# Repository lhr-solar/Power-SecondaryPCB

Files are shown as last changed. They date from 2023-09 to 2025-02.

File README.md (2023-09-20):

# Power-SecondaryPCB 
Author: Pratyush Patra and Jason Kacines

This board takes inputs from the DCDC converter and the Supplemental Battery and selects which source to output to the fuse box. DCDC is the power from the high voltage primary battery pack that gets stepped down to 12V through the DCDC converter. The supplemental battery pack is the low voltage 12V NiMH battery pack. When DCDC is on, the board will select DCDC, and when DCDC is off, the board will select the Supplemental Battery. The supplemental should only be selected during ignition and the fault state. The board selects the source using a 10V zener diode that will breakdown once DCDC is above 10V.

This board also interfaces with both the Supplemental Monitoring PCB and Ignition Switch:
- For the Supplemental Monitoring PCB, this board sends the voltage of the Supplemental Battery out from J1. 
- For the Ignition Switch, this board sends Supplemental Power to the Controls Board through J6, which is then routed back to this board through J7 when the Ignition Switch is changed from the off position. When this signal is sent to J7, it is routed to the gate of Q3 which turns on the NMOS and starts sending power to the fuse box.

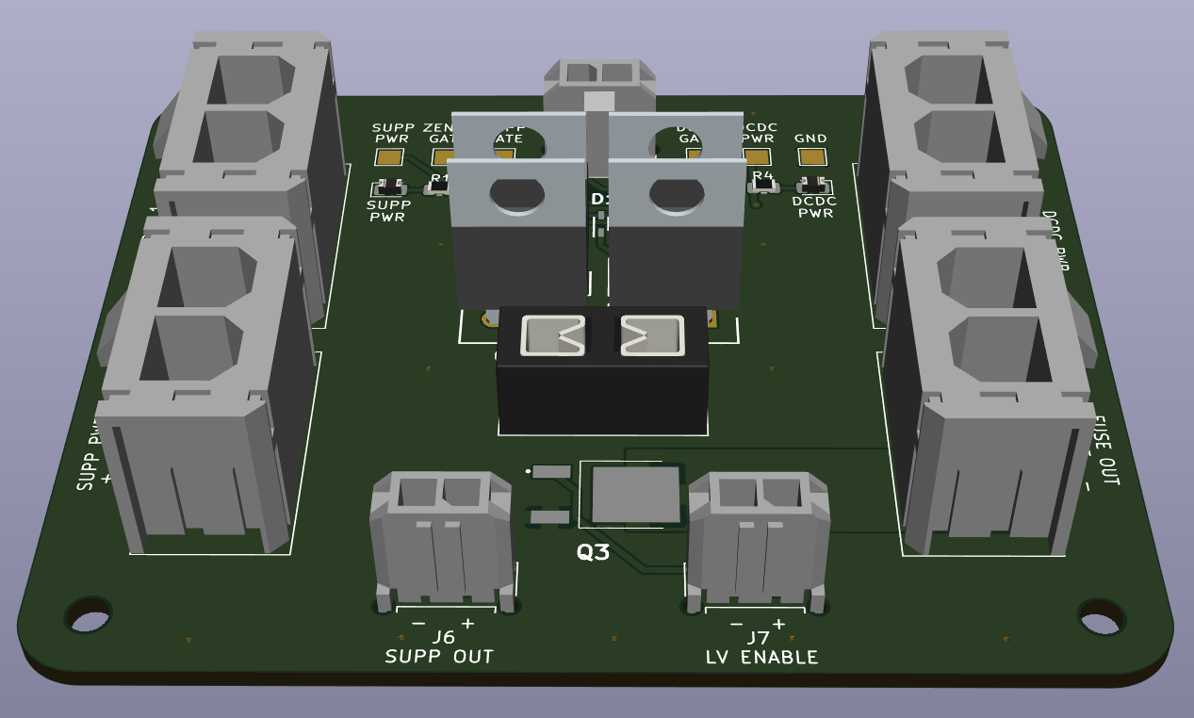
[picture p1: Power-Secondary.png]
Power-Secondary


## BOM
[**Interactive BOM (Must download and open in browser)**](bom/ibom.html)

[**Mouser Cart**](https://www.mouser.com/ProjectManager/ProjectDetail.aspx?AccessID=da938bf7b6)

## Connectors
| # | Name | Type | Ideal Voltage | Notes |
| - | - | - | - | - |
| J1  | SUPP PWR MON | 1x02_P3.00mm_Vertical Female | +12V | 9.9 mm tall |
| J2  | SUPP PWR 1 | 1x02_P7.49mm_Vertical Female |+12V | 14.76 mm tall |
| J3  | SUPP PWR 2 | 1x02_P7.49mm_Vertical Female | +12V | 14.76 mm tall |
| J4  | DCDC PWR | 1x02_P7.49mm_Vertical Female | +12V | 14.76 mm tall |
| J5  | FUSE OUT | 1x02_P7.49mm_Vertical Female | +12V | 14.76 mm tall |
| J6  | SUPP OUT | 1x02_P3.00mm_Vertical Female | +12V | 9.9 mm tall |
| J7  | LV ENABLE | 1x02_P3.00mm_Vertical Female | +12V | 9.9 mm tall |

## PCB


## Schematic


## Additional Notes
The tallest components are the Power MOSFETs(Q1A1, Q1A2, Q1A3, Q1A4) which are 18.5 mm tall and the connectors which are 14.76 mm tall.

## Current Board Concerns(8.26.2023)
- If the two Supplemental Batteries are at different voltage, don't want to charge batteries.
- If the two Supplemental Batteries are above 12V and DCDC is off, don't want to overvolt LV systems. 
        Can tolerate 12.8V.
- Should we use heat sinks for the MOSFET or switch to SMD in case we need to increase current draw in the future
- In future switch to this mosfet, https://www.mouser.com/datasheet/2/196/Infineon_IRFR5305_DataSheet_v01_01_EN-3166466.pdf

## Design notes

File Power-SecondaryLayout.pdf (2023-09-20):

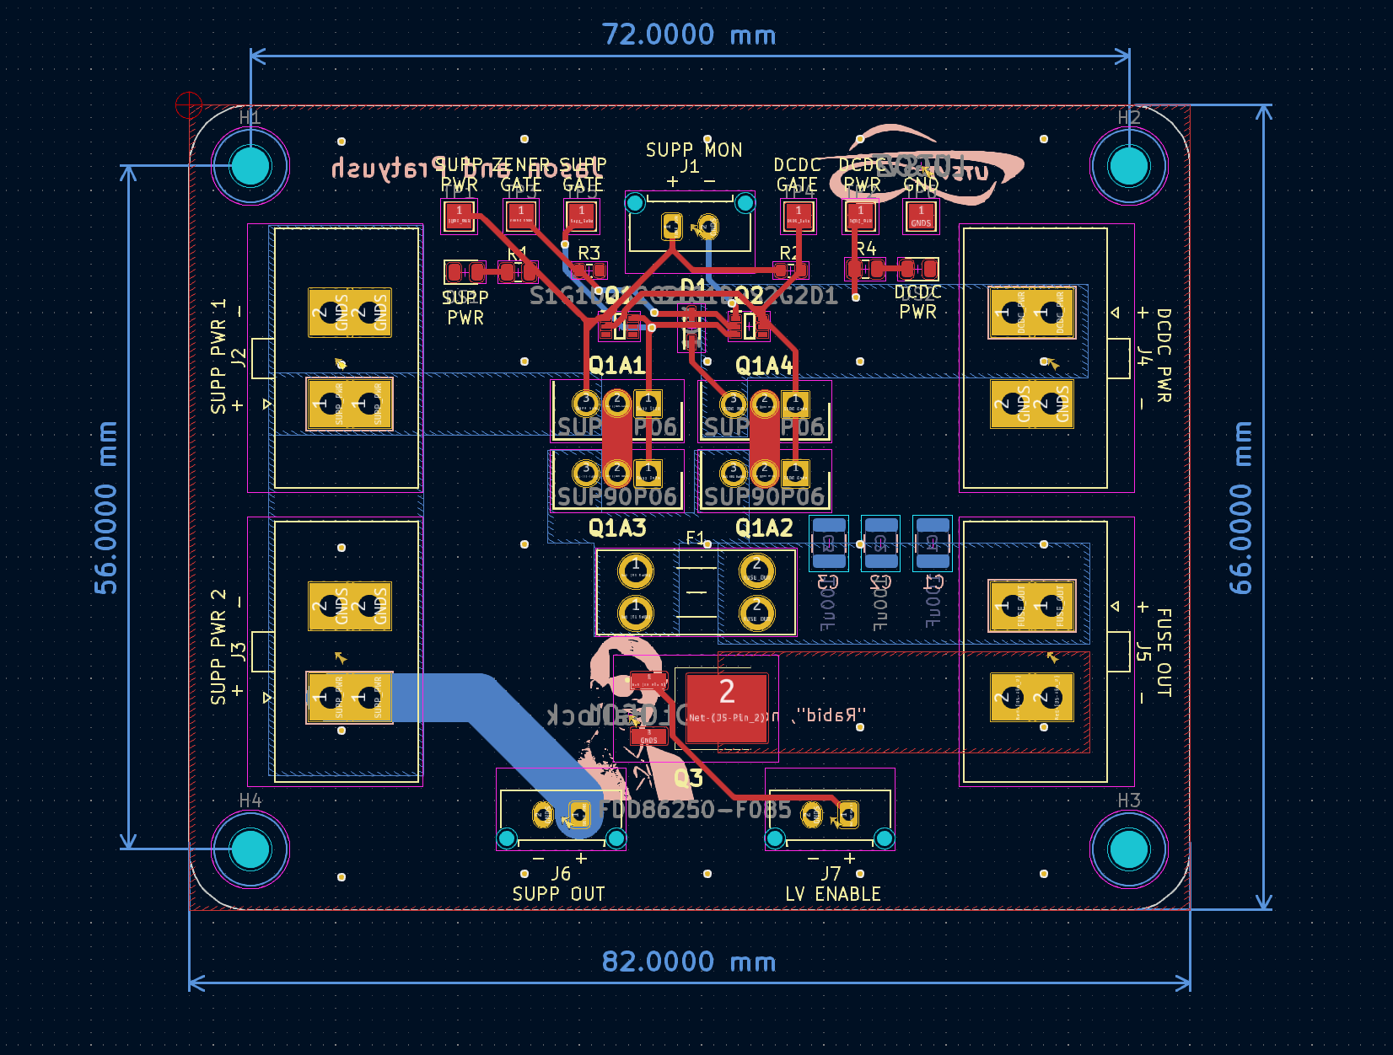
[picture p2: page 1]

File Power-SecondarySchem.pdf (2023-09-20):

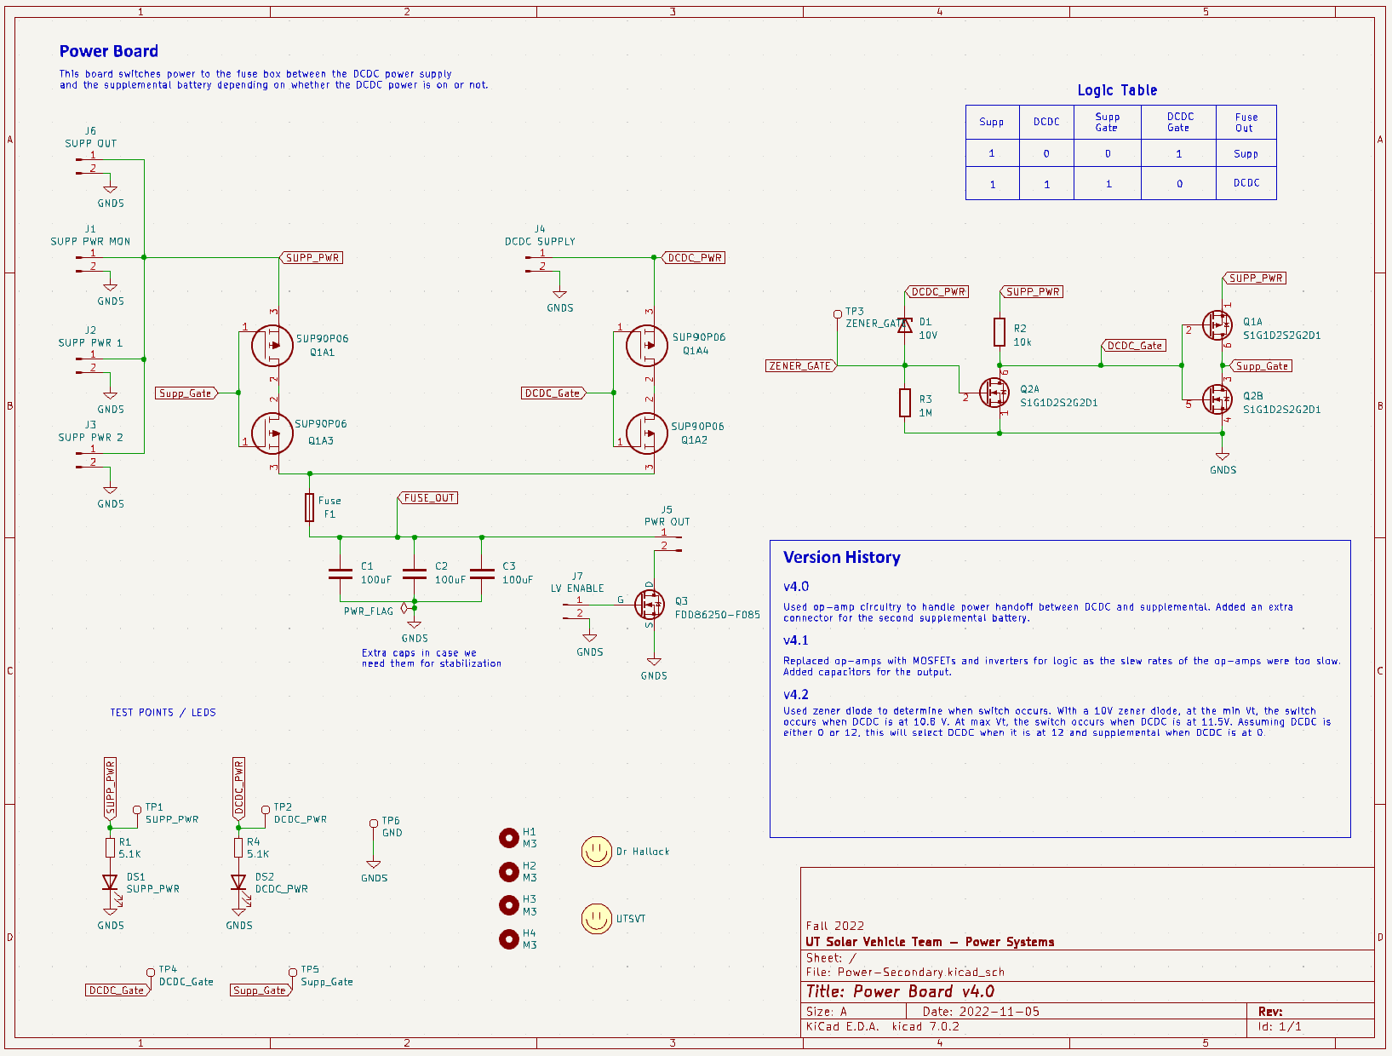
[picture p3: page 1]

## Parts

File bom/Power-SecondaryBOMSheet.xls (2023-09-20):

Mouser # | Mfr. # | Manufacturer | Description | Order Qty. | Price (USD) | Ext.: (USD)
781-SUP90P06-09L-E3 | SUP90P06-09L-E3 | Vishay | Power PMOS(Q1A1, Q1A2, Q1A3, Q1A4) | 4 | $5.56 | $22.24
755-UM6J1NTN | UM6J1NTN | ROHM Semiconductor | Logic PMOS(Q1) | 1 | $0.47 | $0.47
755-UM6K1NTN | UM6K1NTN | ROHM Semiconductor | Logic NMOS(Q2) | 1 | $0.42 | $0.42
538-43160-0102 | 43160-0102 | Molex | Power Connector(J2, J3, J4, J5) | 4 | $1.13 | $4.52
576-0297025.L | 0297025.L | Littelfuse | Fuse | 1 | $0.52 | $0.52
534-3568 | 3568 | Keystone Electronics | Fuse Holder(F1) | 1 | $0.92 | $0.92
604-APTD2012LCGCK | APTD2012LCGCK | Kingbright | LEDs(DS1, DS2) | 2 | $0.40 | $0.80
538-43650-0215 | 43650-0215 | Molex | Monitoring Connector(J1, J6, J7) | 3 | $0.97 | $2.91
80-C0805C106M3PACLR | C0805C106M3PAC7210 | KEMET | Capacitors(C1, C2, C3) | 3 | $0.40 | $1.20
71-CRCW1210J-5.1K-E3 | CRCW12105K10JNEA | Vishay | 5.1k Resistor(R1, R4) | 2 | $0.21 | $0.42
603-RC0603FR-071ML | RC0603FR-071ML | YAGEO | 1M Resistor(R3) | 1 | $0.10 | $0.10
603-AT0603FRD0710KL | AT0603FRD0710KL | YAGEO | 10k Resistor(R2) | 1 | $0.33 | $0.33
771-BZX384-A5V1-QX | BZX384-A5V1-QX | Nexperia | Zener Diode(D1) | 1 | $0.41 | $0.41
863-FDD86250-F085 (https://www.mouser.com/ProductDetail/863-FDD86250-F085) | FDD86250-F085 (https://www.mouser.com/ProductDetail/863-FDD86250-F085) | Onsemi | Power NMOS(Q3) | 1 | $2.28 | $2.28

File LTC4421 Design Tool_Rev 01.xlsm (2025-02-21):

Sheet: Design
Please enter the data in white cells
LTC4421 Design Tool
Primary Input Supply
Highest Priority Input Voltage | 12 | V
Over Voltage Rising | 13 | V
Under Voltage Rising | 11.5 | V
Under Voltage Falling | 10.5 | V
Supply Tolerance | 1 | %
Current Limit | 25 | A
Load Current | 20 | A
OV UV Resistors
For Primary Input Supply
Resistor Netwrok Option | 3
Resistor Tolerance | 2 |  |  |  |  | E192 (0.5%)
Go to line#95 to continue design
Option 1 Resistor Calculations
Resistor Ladder Current | 10.00 | uA
OV1, UVR1, UVF1 Pin Leakage Current | 10.00 | nA
R1 + R2 + R3 + R4 | 1200.00 | kΩ
R1 | 46.15 | kΩ
R2 | 6.02 | kΩ
R3 | 4.97 | kΩ
R4 | 1142.86 | kΩ
Suggested Standard Resistor Values
R1 | 46.40 | kΩ |  |  |  | E96 (1%) | 96 | 1 | 0 | Active E | active %
R2 | 6.04 | kΩ |  |  |  | E192 (0.5%) | 192 | 0.5 | 1 | 192 | 0.5
R3 | 4.99 | kΩ |  |  |  | E192 (0.25%) | 192 | 0.25 | 0
R4 | 1140.00 | kΩ |  |  |  | E192 (0.1%) | 192 | 0.1 | 0
Selected Standard Resistor Values |  |  |  |  |  | min | max
R1 | 38.80 | kΩ |  |  |  | 38.606 | 38.994
R2 | 13.50 | kΩ |  |  |  | 13.4325 | 13.5675
R3 | 4.99 | kΩ |  |  |  | 4.96505 | 5.01495
R4 | 1140.00 | kΩ |  |  |  | 1134.3 | 1145.7
Resistor Tolerance | 0.50 | %
Worst Case Power Dissipation | 0.000114 | W |  |  |  | Resistor Power Rating
Recommended Power Rating of the Resistor | 0.05 | W |  |  |  | 0.05
 |  |  |  |  |  | 0.062
Actual Thresholds | Min | Typ | Max |  |  | 0.1
Actual Over Voltage Rising | 14.97 | 15.43 | 15.89 | V |  | 0.125
Actual Over Voltage Falling | 12.51 | 13.22 | 13.95 | V |  | 0.25
Actual Under Voltage Rising | 11.11 | 11.45 | 11.79 | V |  | 0.5
Actual Under Voltage Falling | 10.14 | 10.45 | 10.76 | V |  | 1
Option 2 Resistor Calculations
Current in Each Resistor Leg | 3.00 | uA
OV1, UVR1, UVF1 Pin Leakage Current | 10.00 | nA
Calculated Resistor Values
R_TOTAL each leg | 4000.00 | kΩ
R1 | 173.91 | kΩ
R2 | 16.56 | kΩ
R3 | 3809.52 | kΩ
R4 | 153.85 | kΩ
R5 | 3846.15 | kΩ
Suggested Standard Resistor Values
R1 | 174.00 | kΩ
R2 | 16.50 | kΩ
R3 | 3830.00 | kΩ
R4 | 154.00 | kΩ
R5 | 3830.00 | kΩ
Selected Standard Resistor Values |  |  |  |  |  | min | max
R1 | 221.00 | kΩ |  |  |  | 219.895 | 222.105
R2 | 110.00 | kΩ |  |  |  | 109.45 | 110.55
R3 | 3650.00 | kΩ |  |  |  | 3631.75 | 3668.25
R4 | 124.00 | kΩ |  |  |  | 123.38 | 124.62
R5 | 3830.00 | kΩ |  |  |  | 3810.85 | 3849.15
Resistor Tolerance | 0.50 | %
Worst Case Power Dissipation | 0.000383 | W
Recommended Power Rating of the Resistor | 0.05 | W
Actual Thresholds | Min | Typ | Max
Actual Over Voltage Rising | 15.47 | 15.94 | 16.42 | V
Actual Over Voltage Falling | 13.58 | 14.35 | 15.13 | V
Actual Under Voltage Rising | 8.74 | 9.01 | 9.27 | V
Actual Under Voltage Falling | 5.84 | 6.01 | 6.19 | V
Option 3 Resistor Calculations
Current in Each Resistor Leg | 2.00 | uA
OV1, UVR1, UVF1 Pin Leakage Current | 10.00 | nA
Calculated Resistor Values
R_TOTAL each leg | 6000.00 | kΩ
R1 | 285.71 | kΩ
R2 | 5714.29 | kΩ
R3 | 260.87 | kΩ
R4 | 5739.13 | kΩ
R5 | 230.77 | kΩ
R6 | 5769.23 | kΩ
Suggested Standard Resistor Values
R1 | 287.00 | kΩ
R2 | 5690.00 | kΩ
R3 | 261.00 | kΩ
R4 | 5760.00 | kΩ
R5 | 232.00 | kΩ
R6 | 5760.00 | kΩ
Selected Standard Resistor Values |  |  |  |  |  | min | max
R1 | 287.00 | kΩ |  |  |  | 285.565 | 288.435
R2 | 5760.00 | kΩ |  |  |  | 5731.2 | 5788.8
R3 | 261.00 | kΩ |  |  |  | 259.695 | 262.305
R4 | 5760.00 | kΩ |  |  |  | 5731.2 | 5788.8
R5 | 215.00 | kΩ |  |  |  | 213.925 | 216.075
R6 | 5760.00 | kΩ |  |  |  | 5731.2 | 5788.8
Resistor Tolerance | 0.50 | %
Worst Case Power Dissipation | 0.000576 | W
Recommended Power Rating of the Resistor | 0.05 | W
Actual Thresholds | Min | Typ | Max
Actual Over Voltage Rising | 13.49 | 13.90 | 14.31 | V
Actual Over Voltage Falling | 12.39 | 12.51 | 12.63 | V
Actual Under Voltage Rising | 11.20 | 11.53 | 11.88 | V
Actual Under Voltage Falling | 10.23 | 10.53 | 10.85 | V
Power Path
Current Limit | 25 | A
 | Min | Typ | Max
Power Dissipation across sense resistor netwrok during current limit | 0.5 | 0.625 | 0.75 | W
Allowed Power Dissipation per Sense Resistor | 1 | W
Desired Maximum Power Dissipation per Sense Resistor | 0.5 | W
Number of resistors required | 1
Equivalent Rsense of the power path should be | 1 | mΩ
Value of each resistor in Rsense should be | 1 | mΩ
Rsense Selected | 1 | mΩ
Sense Resistor Tolarance | 1 | %
Number of Sense Resistors Populated | 1
 | Min | Typ | Max
Effective Rsense | 0.99 | 1.00 | 1.01 | mΩ
 | Min | Typ | Max
Actual Current Limit | 19.80 | 25.00 | 30.30 | A
Actual Power Dissipation per Sense Resistor | 0.39 | 0.62 | 0.93 | W
Snubber
CSN1 | 10.00 | uF
RSN1 | 0.48 | Ω
Resistor Tolerance | E96 (1%)
Suggested RSN1 | 0.5 | Ω
Motor Boating
Voltage Source Input Resistance | 0.0090 | 0.0100 | 0.0110 | Ω
Voltage Drop due to Source Resistance | 0.1782178218 | 0.25 | 0.33 | V
Difference in UVrise and UVfall Voltage | 0.97 | 1.00 | 1.03 | V
High chance of Motor boating. Please set the UVrise and UVfall voltages further apart.
Secondary Input Supply
Secondary Input Voltage | 12 | V
Over Voltage Rising | 13 | V
Under Voltage Rising | 11.5 | V
Under Voltage Falling | 1900-01-09 | V
Supply Tolerance | 1 | %
Current Limit | 16.25 | A
Load Current | 20 | A
Go to line#256 to continue design
Option 1 Resistor Calculations
OV UV Resistors
Resistor Ladder Current | 10.00 | uA
OV2, UVR2, UVF2 Pin Leakage Current | 10.00 | nA
R5+R6+R7+R8 | 1200.00 | kΩ
R5 | 46.15 | kΩ
R6 | 6.02 | kΩ
R7 | 4.97 | kΩ
R8 | 1142.86 | kΩ
Suggested Standard Resistor Values
Resistor Tolerance | E96 (1%)
R5 | 46.40 | kΩ
R6 | 6.04 | kΩ
R7 | 4.99 | kΩ
R8 | 1140.00 | kΩ
Selected Standard Resistor Values |  |  |  |  |  | min | max
R5 | 38.80 | kΩ |  |  |  | 38.606 | 38.994
R6 | 13.50 | kΩ |  |  |  | 13.4325 | 13.5675
R7 | 9.65 | kΩ |  |  |  | 9.60175 | 9.69825
R8 | 1140.00 | kΩ |  |  |  | 1134.3 | 1145.7
Resistor Tolerance | 0.50 | %
Worst Case Power Dissipation | 0.000114 | W
Recommended Power Rating of the Resistor | 0.05 | W
Actual Thresholds | Min | Typ | Max
Actual Over Voltage Rising | 15.03 | 15.49 | 15.95 | V
Actual Over Voltage Falling | 12.51 | 13.22 | 13.95 | V
Actual Under Voltage Rising | 11.15 | 11.49 | 11.83 | V
Actual Under Voltage Falling | 9.42 | 9.70 | 9.99 | V
Option 2 Resistor Calculations
Current in Each Resistor Leg | 3.00 | uA
OV1, UVR1, UVF1 Pin Leakage Current | 10.00 | nA
Calculated Resistor Values
R_TOTAL each leg | 4000.00 | kΩ
R6 | 173.91 | kΩ
R7 | 16.56 | kΩ
R8 | 3809.52 | kΩ
R9 | 153.85 | kΩ
R10 | 3846.15 | kΩ
Suggested Standard Resistor Values
R6 | 174.00 | kΩ
R7 | 16.50 | kΩ
R8 | 3830.00 | kΩ
R9 | 154.00 | kΩ
R10 | 3830.00 | kΩ
Selected Standard Resistor Values |  |  |  |  |  | min | max
R6 | 442.00 | kΩ |  |  |  | 439.79 | 444.21
R7 | 221.00 | kΩ |  |  |  | 219.895 | 222.105
R8 | 7320.00 | kΩ |  |  |  | 7283.4 | 7356.6
R9 | 110.00 | kΩ |  |  |  | 109.45 | 110.55
R10 | 7870.00 | kΩ |  |  |  | 7830.65 | 7909.35
Resistor Tolerance | 0.50 | %
Worst Case Power Dissipation | 0.000787 | W
Recommended Power Rating of the Resistor | 0.05 | W
Actual Thresholds | Min | Typ | Max
Actual Over Voltage Rising | 35.20 | 36.27 | 37.36 | V
Actual Over Voltage Falling | 30.89 | 32.65 | 34.43 | V
Actual Under Voltage Rising | 8.77 | 9.03 | 9.30 | V
Actual Under Voltage Falling | 5.85 | 6.02 | 6.20 | V
Option 3 Resistor Calculations
Current in Each Resistor Leg | 2.00 | uA
OV1, UVR1, UVF1 Pin Leakage Current | 10.00 | nA
Calculated Resistor Values
R_TOTAL each leg | 6000.00 | kΩ
R7 | 285.71 | kΩ
R8 | 5714.29 | kΩ
R9 | 260.87 | kΩ
R10 | 5739.13 | kΩ
R11 | 230.77 | kΩ
R12 | 5769.23 | kΩ
Suggested Standard Resistor Values
R7 | 287.00 | kΩ
R8 | 5690.00 | kΩ
R9 | 261.00 | kΩ
R10 | 5760.00 | kΩ
R11 | 232.00 | kΩ
R12 | 5760.00 | kΩ
Selected Standard Resistor Values |  |  |  |  |  | min | max
R7 | 287.00 | kΩ |  |  |  | 285.565 | 288.435
R8 | 5690.00 | kΩ |  |  |  | 5661.55 | 5718.45
R9 | 261.00 | kΩ |  |  |  | 259.695 | 262.305
R10 | 5760.00 | kΩ |  |  |  | 5731.2 | 5788.8
R11 | 232.00 | kΩ |  |  |  | 230.84 | 233.16
R12 | 5760.00 | kΩ |  |  |  | 5731.2 | 5788.8
Resistor Tolerance | 0.50 | %
Worst Case Power Dissipation | 0.000576 | W
Recommended Power Rating of the Resistor | 0.05 | W
Actual Thresholds | Min | Typ | Max
Actual Over Voltage Rising | 12.53 | 12.91 | 13.30 | V
Actual Over Voltage Falling | 11.51 | 11.62 | 11.73 | V
Actual Under Voltage Rising | 11.20 | 11.53 | 11.88 | V
Actual Under Voltage Falling | 10.11 | 10.41 | 10.72 | V
Overvoltage threshold is lower than the allowed supply voltage tolerance. Chose a higher Overvoltage Threshold
Power Path
Current Limit | 16.25 | A
 | Min | Typ | Max
Power Dissipation across sense resistor netwrok during current limit | 0.325 | 0.40625 | 0.4875 | W
Allowed Power Dissipation per Sense Resistor | 1 | W
Desired Maximum Power Dissipation per Sense Resistor | 0.5 | W
Number of resistors required | 0
Equivalent Rsense of the power path should be | 1.538461538 | mΩ
Value of each resistor in Rsense should be | 0 | mΩ
Rsense Selected | 1 | mΩ
Sense Resistor Tolarance | 1 | %
Number of Sense Resistors Populated | 1
The equivalent Rsense with the selected value of Rsense resistor and number of Rsense resistors isdifferent than the desired value of equivalent Rsense. Please pay attention to current limit value as it will be different than the desired value
 | Min | Typ | Max
Effective Rsense | 0.99 | 1.00 | 1.01 | mΩ
 | Min | Typ | Max
Actual Current Limit | 19.80 | 25.00 | 30.30 | A
Actual Power Dissipation per Sense Resistor | 0.39 | 0.62 | 0.93 | W
Snubber
CSN2 | 10.00 | uF
RSN2 | 0.48 | Ω
Resistor Tolerance | E96 (1%)
Suggested RSN2 | 0.5 | Ω
Motor Boating
Voltage Source Input Resistance | 0.0090 | 0.0100 | 0.0110 | Ω
Voltage Drop due to Source Resistance | 0 | 0.00 | 0.00 | V
Difference in UVrise and UVfall Voltage | 1.74 | 1.79 | 1.84 | V
Low chance of Motor Boating
Input Supply Validity
Desired Qualification Time for Validity | 16.00 | ms
Required Cap on Qual Pin | 1.00 | nF
Closest Standard Cap Value | 1.50 | nF
Cap Value Populated on Qual Pin | 1.50 | nF
Qual Pin Cap Tolerance | 1.00 | %
 | Min | Typ | Max
Actual Qualification Time for Validity | 15.80 | 23.94 | 35.46 | ms
Output Stage
Output Cap ESR | 42 | mΩ
Allowed Output Voltage Droop during switchover | 1200 | mV
During switch over, Output voltage droop due to cap ESR | 840 | mV
Minimum Cout Required | 833.333 | uF
Closest Standard Cap value | 1000.000 | uF
Cout Selected | 1200 | uF
Cap Tolerance | 20 | %
 | Min | Typ | Max
Actual Total Output Voltage Droop during switchover | 1048.333333 | 1090 | 1152.5 | mV
Primary Side Timer cap selection
 | Min | Typ | Max
Time to charge the output cap from 0V to 12V using primary supply | 1118.117647 | 2880 | -87264 | us
Primary Supply Timer Cap Should be more than | -1586.62 | nF
Closest Standard Cap Value | 1.00 | nF
Primary Supply Timer Cap Populated | 10000 | nF
Timer Cap Tolerance | 5 | %
 | Min | Typ | Max
Primary Supply Timer | 522500 | 830000 | 1312500 | us
Primary Side MOSFET Selection and SOA Limit Calculation
Select LTC4421 Data Sheet MOSFET Used from drop down menu. If different MOSFET used, select "OTHER MOSFET" | OTHER MOSFET
 |  |  | 33 | FALSE
 |  |  | 1ms | 10ms
Enter MOSFET 1ms and 10ms Data Sheet SOA currents at VDS = Over Voltage Rising |  |  | 200 | 90 | Amps
 |  |  | T_ambient | T_junction max
Enter ambient and Maximum MOSFET Junction Temperatures |  |  | 35 | 175 | C
MOSFET SOA Current @ 25C and Max Primary Supply Timer | 16.58487389 | Amps
MOSFET SOA Current @ T_ambient and Max Primary Supply Timer | 15.47921563 | Amps
Maximum Actual Current Limit | 30.3030303 | Amps
MOSFET SOA margin @ 25C | -45.26991618 | % | Warning: MOSFET SOA may be exceeded for resistive output shorts
MOSFET SOA margin @ T_ambient | -48.91858843 | % | Warning: MOSFET SOA may be exceeded for resistive output shorts
Secondary Side Timer cap selection
 | Min | Typ | Max
Time to charge the output cap from 0V to 12V using secondary supply | 1118.117647 | 2880 | -87264 | us
Secondary Supply Timer Cap Should be more than | -1586.62 | nF
Closest Standard Cap Value | 1.00 | nF
Secondary Supply Timer Cap Populated | 33 | nF
Timer Cap Tolerance | 5 | %
 | Min | Typ | Max
Secondary Supply Timer | 1724.25 | 2739 | 4331.25 | us
Secondary Side MOSFET Selection and SOA Limit Calculation
 |  |  | Data Sheet MOSFET SOA Drain Current at Overvoltage
Select LTC4421 Data Sheet MOSFET Used from drop down menu. If different MOSFET used, select "OTHER MOSFET" | SiR158 |  | 1ms | 10ms
 |  |  | 36.82 | 14.42 | Amps
 |  |  | T_ambient | T_junction max
 | Enter Ambient Temperature |  | 33 | 150 | C
 |  |  | 200 | 90
 |  |  | 35 | 175
MOSFET SOA Current @ 25C and Max Primary Supply Timer | 20.274009 | Amps
MOSFET SOA Current @ T_ambient and Max Primary Supply Timer | 18.97647242 | Amps
Maximum Actual Current Limit | 30.3030303 | Amps
MOSFET SOA margin @ 25C | -33.0957703 | % | Warning: MOSFET SOA may be exceeded for resistive output shorts
MOSFET SOA margin @ T_ambient | -37.377641 | % | Warning: MOSFET SOA may be exceeded for resistive output shorts

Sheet: BOM and Export
Component Name | Value | Units | Tolarance (%) | Power Rating (W) | Quantity
R1 | 287.00 | kΩ | 0.5 | 0.05 | 1
R2 | 5760.00 | kΩ | 0.5 | 0.05 | 1
R3 | 261.00 | kΩ | 0.5 | 0.05 | 1
R4 | 5760.00 | kΩ | 0.5 | 0.05 | 1
R5 | 215.00 | kΩ | 0.5 | 0.05 | 1
R6 | 5760.00 | kΩ | 0.5 | 0.05 | 1
R7 | 287.00 | kΩ | 0.5 | 0.05 | 1
R8 | 5690.00 | kΩ | 0.5 | 0.05 | 1
R9 | 261.00 | kΩ | 0.5 | 0.05 | 1
R10 | 5760.00 | kΩ | 0.5 | 0.05 | 1
R11 | 232.00 | kΩ | 0.5 | 0.05 | 1
R12 | 5760.00 | kΩ | 0.5 | 0.05 | 1
RSENSE_1 | 1 | mΩ | 0.5 | 1 | 1
RSENSE_2 | 1.0 | mΩ | 1 | 1 | 1
RSN1 | 0.48 | Ω | 0.5 | 0.05 | 1
RSN2 | 0.48 | Ω | 0.5 | 0.05 | 1
Component Name | Value | Units | Tolarance (%) | Voltage Rating (V) | Quantity
C_QUAL | 1.50 | nF | 1 | 25V | 1
C_TMR_1 | 10000 | nF | 5 | 25V | 1
C_TMR_2 | 33 | nF | 5 | 25V | 1
C_INTVcc | 1 | uF | 5 | 50V | 1
C_EXTVcc | 0.1 | uF | 5 | 50V | 1
C_CPO | 1 | uF | 5 | 50V | 1
CSN1 | 10 | uF | 5 | 50V | 1
CSN2 | 10 | uF | 5 | 50V | 1
CGS1 | 47 | nF | 5 | 50V | 1
CGS2 | 47 | nF | 5 | 50V | 1
COUT | 1200 | uF | 20 | 50V | 1
System Parameters
Primary Supply Voltage | 12 | V
Secondary Supply Voltage | 12 | V
Export to LTspice will only work if LTspice software is installed

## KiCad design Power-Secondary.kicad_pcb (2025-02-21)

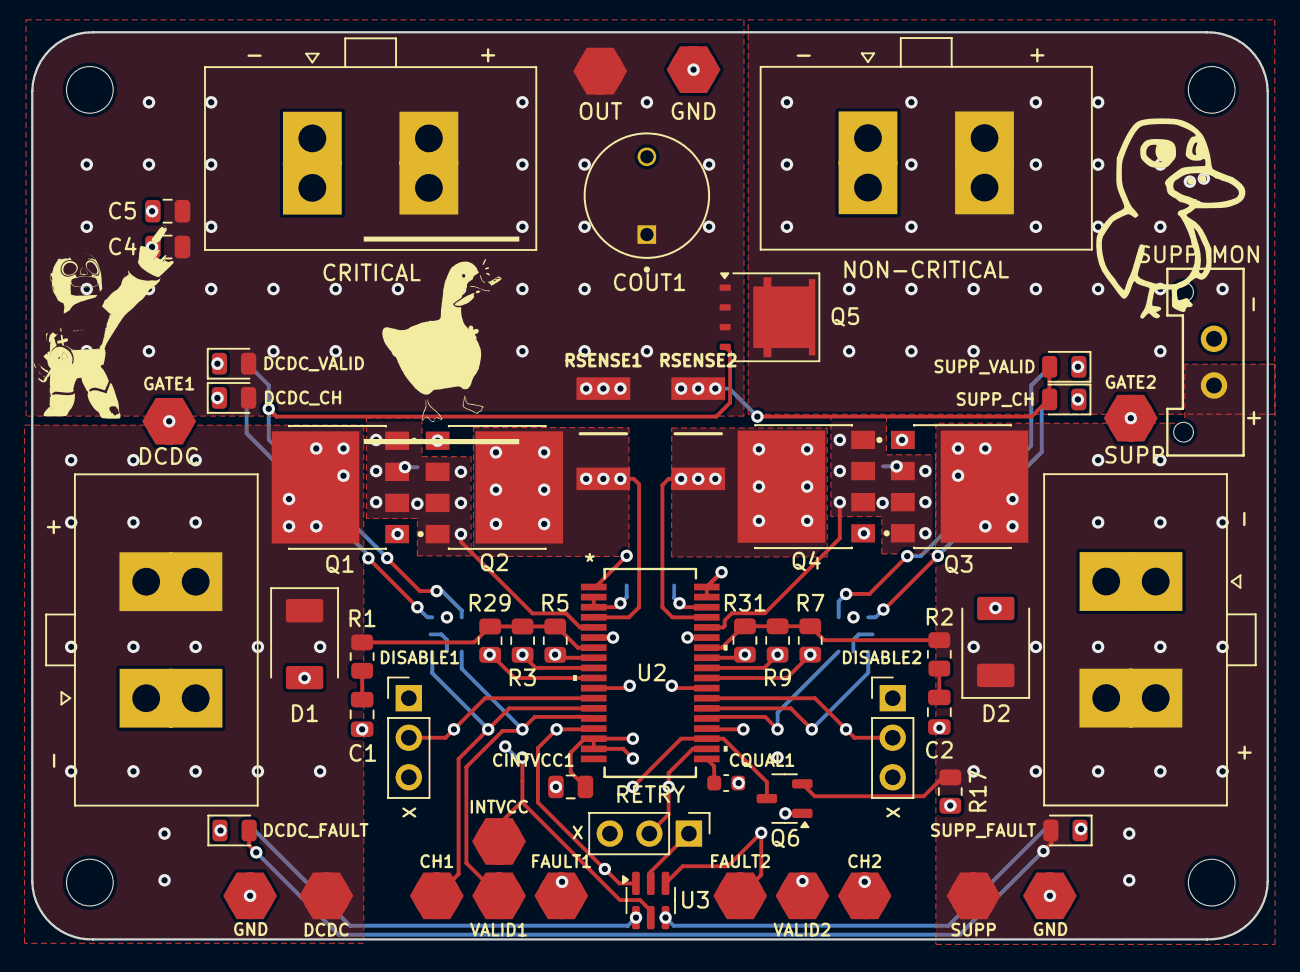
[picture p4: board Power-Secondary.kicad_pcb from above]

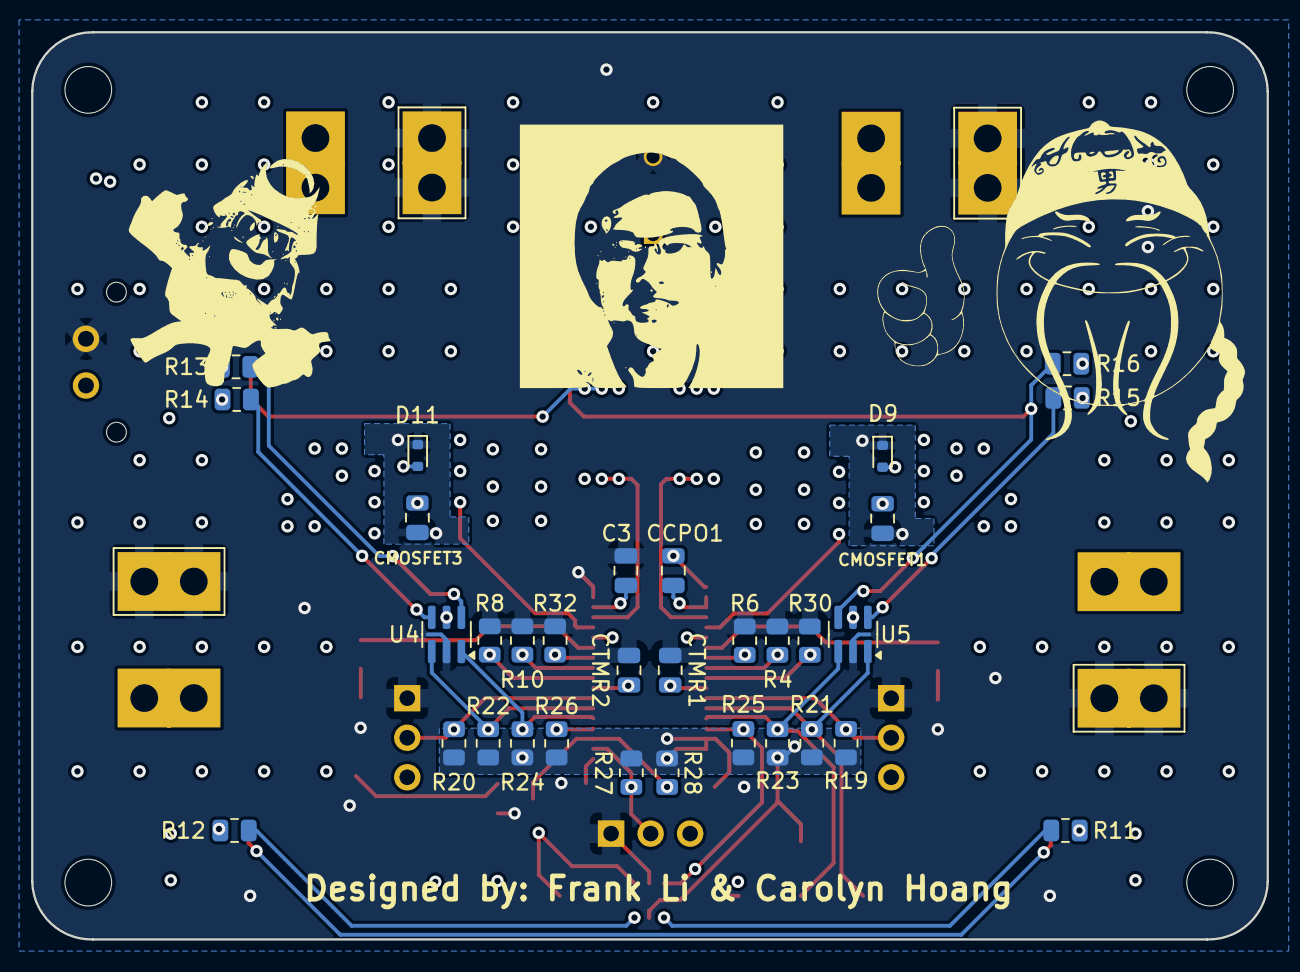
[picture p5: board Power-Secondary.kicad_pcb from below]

Board: 4 copper layers, 79.4 x 58.3 mm, 91 parts (32 on the bottom side), 46 nets.

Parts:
C1, C2, C4: 10u; C_0805_2012Metric
C3, C5: 0.1u; C_0805_2012Metric
CCPO1: 1u; C_0805_2012Metric
CH1, CH2: TestPoint; TestPoint_HEX_3mmID
CINTVCC1: 1u; C_0805_2012Metric
CMOSFET1, CMOSFET3: 10u; C_0805_2012Metric
COUT1: 1.2m; EEUFS1C122LB
CQUAL1: 500p; C_0603_1608Metric
CRITICAL: PowerConn; Molex_Sabre_43160-0102_1x02_P7.49mm_Vertical
CTMR1, CTMR2: 10u; C_0805_2012Metric
D1, D2: SMBJ15D-M3I; P26_DO-214AA_SMB
D9, D11: D_Zener; D_SOD-523
DCDC: TestPoint; TestPoint_HEX_3mmID
DCDC#2: PowerConn; Molex_Sabre_43160-0102_1x02_P7.49mm_Vertical
DCDC_CH: LED; LED_0805_2012Metric
DCDC_FAULT: LED; LED_0805_2012Metric
DCDC_VALID: LED; LED_0805_2012Metric
DISABLE1: DIS1 Jumper; PinHeader_1x03_P2.54mm_Vertical
DISABLE2: DIS2 Jumper; PinHeader_1x03_P2.54mm_Vertical
FAULT1, FAULT2: TestPoint; TestPoint_HEX_3mmID
GATE1, GATE2: TestPoint; TestPoint_HEX_3mmID
GND: TestPoint; TestPoint_HEX_3mmID
H1, H2, H3, H4: MountingHole; MountingHole_3mm
INTVCC: TestPoint; TestPoint_HEX_3mmID
NON-CRITICAL: PowerConn; Molex_Sabre_43160-0102_1x02_P7.49mm_Vertical
OUT: TestPoint; TestPoint_HEX_3mmID
Q1, Q2, Q3, Q4: SQJQ140E-T1_GE3; TO200P800X182-5N
Q5: SQJ141ELP; PowerPAK_SO-8L_Single
Q6: PMOS; SOT-23-3
R1, R2: 1.2; R_0805_2012Metric
R3, R5, R7, R9, R29, R31: 5.76M; R_0805_2012Metric
R4, R10: 261K; R_0805_2012Metric
R6, R32: 287K; R_0805_2012Metric
R8, R30: 215K; R_0805_2012Metric
R11, R12, R13, R14, R15, R16, R17, R19, R20, R21, R22, R23, R24, R25, R26, R27, R28: 100K; R_0805_2012Metric
RETRY: RETRY Jumper; PinHeader_1x03_P2.54mm_Vertical
RSENSE1, RSENSE2: 1m; RESC6432X89N
SUPP: PowerConn; Molex_Sabre_43160-0102_1x02_P7.49mm_Vertical
SUPP MON: PowerConn; Molex_MicroFit3.0_1x2xP3.00mm_PolarizingPeg_Vertical
SUPP#2: TestPoint; TestPoint_HEX_3mmID
SUPP_CH: LED; LED_0805_2012Metric
SUPP_FAULT: LED; LED_0805_2012Metric
SUPP_VALID: LED; LED_0805_2012Metric
U2: LTC4421CG-PBF; G_05-08-1640_ADI
U3, U4, U5: 74LVC2G07GV,125; ROHM_SOT-457_ClockwisePinNumbering
VALID1, VALID2: TestPoint; TestPoint_HEX_3mmID

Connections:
/GATE1: CMOSFET1.1, D9.1 (K), GATE1.1, Q1.1, Q2.1, U2.6 (GATE1)
/GATE2: CMOSFET3.1, D11.1 (K), GATE2.1, Q3.1, Q4.1, U2.31 (GATE2)
/INTVCC: CINTVCC1.1, INTVCC.1, R19.1, R20.1, R21.1, R22.1, R23.1, R24.1, R25.1, R26.1, R27.1, R28.1, U2.16 (CASIN), U2.17 (INTVCC), U3.5 (VCC), U4.5 (VCC), U5.5 (VCC)
/LTC4421/CH1: CH1.1, R21.2, U2.13 (*CH1), U5.1 (1A)
/LTC4421/CH2: CH2.1, R22.2, U2.24 (*CH2), U4.3 (2A)
/LTC4421/CPO: CCPO1.1, U2.1 (CPO)
/LTC4421/DISABLE1: DISABLE1.2 (C), R19.2, U2.12 (*DISABLE1)
/LTC4421/DISABLE2: DISABLE2.2 (C), R20.2, U2.25 (*DISABLE2)
/LTC4421/FAULT1: FAULT1.1, R25.2, U2.15 (*FAULT1), U3.1 (1A)
/LTC4421/FAULT2: FAULT2.1, R26.2, U2.22 (*FAULT2), U3.3 (2A)
/LTC4421/Non-Crit Drive: Q5.4, R16.2, U5.4 (2Y)
/LTC4421/OV1: R29.2, R30.1, U2.10 (OV1)
/LTC4421/OV2: R7.2, R8.1, U2.27 (OV2)
/LTC4421/QUAL: CQUAL1.1, U2.19 (QUAL)
/LTC4421/RETRY: R27.2, RETRY.2 (C), U2.20 (RETRY)
/LTC4421/SENSE1: Q2.5, RSENSE1.1, U2.4 (SENSE1)
/LTC4421/SENSE2: Q4.5, RSENSE2.1, U2.33 (SENSE2)
/LTC4421/TMR1: CTMR1.1, U2.11 (TMR1)
/LTC4421/TMR2: CTMR2.1, U2.26 (TMR2)
/LTC4421/UVF1: R5.2, R6.1, U2.8 (UVF1)
/LTC4421/UVF2: R31.2, R32.1, U2.29 (UVF2)
/LTC4421/UVR1: R3.2, R4.1, U2.9 (UVR1)
/LTC4421/UVR2: R9.2, R10.1, U2.28 (UVR2)
/LTC4421/VALID1: R23.2, U2.14 (*VALID1), U5.3 (2A), VALID1.1
/LTC4421/VALID2: R24.2, U2.23 (*VALID2), U4.1 (1A), VALID2.1
/OUT: C3.1, C4.1, C5.1, CCPO1.2, COUT1.1, CRITICAL.2, DCDC_CH.2 (A), DCDC_VALID.2 (A), OUT.1, Q5.1, Q5.2, Q5.3, RSENSE1.2, RSENSE2.2, SUPP_CH.2 (A), SUPP_VALID.2 (A), U2.2 (CPOREF), U2.3 (OUT1), U2.34 (OUT2)
/SHDN: Q6.3 (S), R28.2, U2.21 (*SHDN)
/SOURCE1: CMOSFET1.2, D9.2 (A), Q1.2, Q1.3, Q1.4, Q2.2, Q2.3, Q2.4, U2.5 (SOURCE1)
/SOURCE2: CMOSFET3.2, D11.2 (A), Q3.2, Q3.3, Q3.4, Q4.2, Q4.3, Q4.4, U2.32 (SOURCE2)
/V1: D1.1 (K), DCDC.1, DCDC#2.2, Q1.5, R1.1, R3.1, R5.1, R29.1, U2.7 (V1)
/V2: D2.1 (K), DCDC_FAULT.2 (A), Q3.5, Q6.2 (G), R2.1, R7.1, R9.1, R17.1, R31.1, SUPP.2, SUPP MON.1, SUPP#2.1, SUPP_FAULT.2 (A), U2.30 (V2)
GND: C1.2, C2.2, C3.2, C4.2, C5.2, CINTVCC1.2, COUT1.2, CQUAL1.2, CRITICAL.1, CTMR1.2, CTMR2.2, D1.2 (A), D2.2 (A), DCDC#2.1, DISABLE1.1 (A), DISABLE2.1 (A), GND.1, NON-CRITICAL.1, Q6.1 (D), R4.2, R6.2, R8.2, R10.2, R17.2, R30.2, R32.2, RETRY.1 (A), SUPP.1, SUPP MON.2, U2.35 (GND), U2.36 (EXTVCC), U3.2 (GND), U4.2 (GND), U5.2 (GND)
unnamed: C1.1, R1.2
unnamed: C2.1, R2.2
unnamed: DCDC_FAULT.1 (K), R11.1
unnamed: R12.1, SUPP_FAULT.1 (K)
unnamed: R13.1, SUPP_VALID.1 (K)
unnamed: R14.1, SUPP_CH.1 (K)
unnamed: DCDC_CH.1 (K), R15.1
unnamed: DCDC_VALID.1 (K), R16.1
unnamed: NON-CRITICAL.2, Q5.5
unnamed: R11.2, U3.6 (1Y)
unnamed: R12.2, U3.4 (2Y)
unnamed: R13.2, U4.6 (1Y)
unnamed: R14.2, U4.4 (2Y)
unnamed: R15.2, U5.6 (1Y)

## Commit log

2020-08-02 Separate the primary battery board to its own repo.
    [BOM.csv, BPS-Nucleo.kicad_pcb, BPS-Nucleo.sch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]
2020-10-10 Add STEP model of board
    [Secondary-Power.step]
2020-10-17 Secondary board v1.1 (#2)
    * Updated PBB to better match Hannah's standards
    * Adds power planes to secondary power board
    * Updates schematics to match secondary power board v1.1
    * Adds gitignore file
    * Creates and deletes gerbers for release and finishes routing tracks
    * Adds dimensions to PCB
    [PBB.kicad_pcb, Power-Secondary.kicad_pcb, Power-Secondary.sch]
2020-10-17 Adds pdf and png of documentation of schematic and pcb
2021-01-11 Secondary Power Board CDR Edits (#3)
    * Combines disconnect and main supply for BPS into one connector
    * Rearranges labels and adds gerbers
    [Power-Secondary-B_Cu.gbr, Power-Secondary-B_Mask.gbr, Power-Secondary-B_Paste.gbr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]
2021-01-23 adds 3D models
    [Power-Secondary.kicad_pcb]
2023-02-06 Paj (#4)
    * first
    * secondary power pcb v2
    Changed schematic, removed unnecessary/old files
    * version 3
    * v3 update
    * v3 revision
    * added planes
    * gerbers and fuse
    * QUAC and readme
    * added supp monitor connector
    * gerbers
    * removed excess
    * updated gerbers and fixed clearence issues
    * Added BOM
    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
    [Power-Secondary-B_Cu.gbr, Power-Secondary-B_Mask.gbr, Power-Secondary-B_Paste.gbr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]
2023-03-09 new diode board
    [Power-Secondary.kicad_pcb]
2023-03-10 New design made
    [Power-Secondary.kicad_pcb, Power-Secondary.kicad_sch]
2023-03-10 Fixed PMOS orientation, added testpoints
    [Power-Secondary.kicad_pcb, Power-Secondary.kicad_sch]
2023-03-10 Made gerber files. Added dimensions
    [Power-Secondary-B_Cu.gbr, Power-Secondary-B_Mask.gbr, Power-Secondary-B_Paste.gbr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]
2023-03-10 Made some traces wider
    [Power-Secondary-B_Cu.gbr, Power-Secondary-B_Mask.gbr, Power-Secondary-B_Paste.gbr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]
2023-09-20 V4.2 (#7)
    * Updated submodule
    * Updated QAC
    * Deleted extra QAC
    * Updated BOM
    * Added images of PCB schematic and layout
    * Updated constraints
    * Updated README with BOM
    * Updated images
    * Fixed README
    * Updated Datasheets
    * Added Excel BOM
    * Fixed DRC and ERC errors in Kicad 7
    * Updated datasheets
    * Updated 3D models
    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
    [Power-Secondary-B_Cu.gbl, Power-Secondary-B_Cu.gbr, Power-Secondary-B_Mask.gbr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]
2023-09-21 V4.2 (#8)
    * Updated README and version history
    * Fix BOM in README
    * Replaced resistor divider with zener
    * Corrected gate labels
    * Updated layout with zener diode
    * Updated schematic to interface with ignition switch
    * Updated layout
    * Updated pdfs
    * Updated BOMs
    * Updated README
    * Fixed README format
    * Rerouted t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
    [Power-Secondary-B_Cu.gbl, Power-Secondary-B_Mask.gbs, Power-Secondary-B_Paste.gbp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]
2025-02-21 Ltc4421 v1.0 (#12)
    * LTC4421 Symbol creation
    * early sch
    * early sch
    * changes
    * Improved organization of sch
    * added circuitry for sch
    * Added MOSFET to symbol library
    * Finished sch
    * footprint assignments
    * changes to Power Board sch
    * CAD models, symbols update, and footprints
    * Pull up and Pull down configs for VALID, DISABLE, SHDN, RETRY
    * small changes
    * Library fixes and sch changes
    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
    [LTC4421 Design Tool_Rev 01.xlsm, LTC4421.kicad_sch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]
